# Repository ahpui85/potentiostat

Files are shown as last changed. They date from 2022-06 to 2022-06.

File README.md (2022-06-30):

This project is aimed to design a miniaturized, an inexpensive, and easy to use electrochemical potentiostat to meet the demand for on-site measurement. Integration of the potentiostat to a mobile device makes the measuring device portable. Bluetooth technology is chosen to communicate with mobile device as it features both low power and wireless communication. Therefore the potentiostat consist of the following modules: 
a) Front-end module which drives the sensor and the measures the current. 
b) power module that generates the stable voltage. 
c) A back-end module comprised of microcontroller (MCU) to control voltage, digitize and process the data, and Bluetooth module to communicate with the mobile devices. 
We have created a guide to design, layout, assemble, troubleshoot, and test a Printed circuit board (PCB) that is able conduct electrochemistry measurement. This step by step guide will ultimately allow anyone to develop a portable, accessible, and low-cost potentiostat based on Arduino, together with mobile phone application to control the potentiostat.

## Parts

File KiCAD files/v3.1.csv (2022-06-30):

Reference | Value | Footprint | Datasheet
P1 | Digital | Socket_Arduino_Nano:Socket_Strip_Arduino_1x15
P2 | Analog | Socket_Arduino_Nano:Socket_Strip_Arduino_1x15
R1 | 510ohm | Resistor_THT:R_Axial_DIN0204_L3.6mm_D1.6mm_P7.62mm_Horizontal | ~
R2 | 200ohm | Resistor_THT:R_Axial_DIN0204_L3.6mm_D1.6mm_P7.62mm_Horizontal | ~
R3 | 510ohm | Resistor_THT:R_Axial_DIN0204_L3.6mm_D1.6mm_P7.62mm_Horizontal | ~
R4 | 200ohm | Resistor_THT:R_Axial_DIN0204_L3.6mm_D1.6mm_P7.62mm_Horizontal | ~
R6 | 250ohm | Resistor_THT:R_Axial_DIN0204_L3.6mm_D1.6mm_P7.62mm_Horizontal | ~
R5 | 12k | Resistor_THT:R_Axial_DIN0204_L3.6mm_D1.6mm_P7.62mm_Horizontal | ~
C1 | 100nf | Capacitor_THT:C_Axial_L3.8mm_D2.6mm_P7.50mm_Horizontal | ~
C2 | 470nf | Capacitor_THT:C_Axial_L3.8mm_D2.6mm_P7.50mm_Horizontal | ~
C3 | 470nf | Capacitor_THT:C_Axial_L3.8mm_D2.6mm_P7.50mm_Horizontal | ~
C4 | 10micron | Capacitor_THT:CP_Radial_D5.0mm_P2.00mm | ~
C5 | 10micron | Capacitor_THT:CP_Radial_D5.0mm_P2.00mm | ~
C7 | 10micron | Capacitor_THT:CP_Radial_D5.0mm_P2.00mm | ~
Ufilter1 | LM741 | Package_DIP:DIP-8_W7.62mm | http://www.ti.com/lit/ds/symlink/lm741.pdf
Upoten1 | LM324 | Package_DIP:DIP-14_W7.62mm | http://www.ti.com/lit/ds/symlink/lm2902-n.pdf
J1 | Conn_01x03 | Connector_PinHeader_2.54mm:PinHeader_1x03_P2.54mm_Vertical | ~
IC1 | ICL7660 | Package_DIP:DIP-8_W7.62mm | http://datasheets.maximintegrated.com/en/ds/ICL7660-MAX1044.pdf
IC2 | ICL7660 | Package_DIP:DIP-8_W7.62mm | http://datasheets.maximintegrated.com/en/ds/ICL7660-MAX1044.pdf
C6 | 10micron | Capacitor_THT:CP_Radial_D5.0mm_P2.00mm | ~
P6 | CONN_01X01 | Socket_Arduino_Nano:1pin_Nano
P5 | CONN_01X01 | Socket_Arduino_Nano:1pin_Nano
P4 | CONN_01X01 | Socket_Arduino_Nano:1pin_Nano
P3 | CONN_01X01 | Socket_Arduino_Nano:1pin_Nano
J5 | Conn_01x06_Female | Connector_PinSocket_2.54mm:PinSocket_1x06_P2.54mm_Vertical | ~
J2 | Conn_01x02_Female | Connector_PinSocket_2.54mm:PinSocket_1x02_P2.54mm_Vertical | ~
JP1 | Jumper | TestPoint:TestPoint_2Pads_Pitch2.54mm_Drill0.8mm | ~

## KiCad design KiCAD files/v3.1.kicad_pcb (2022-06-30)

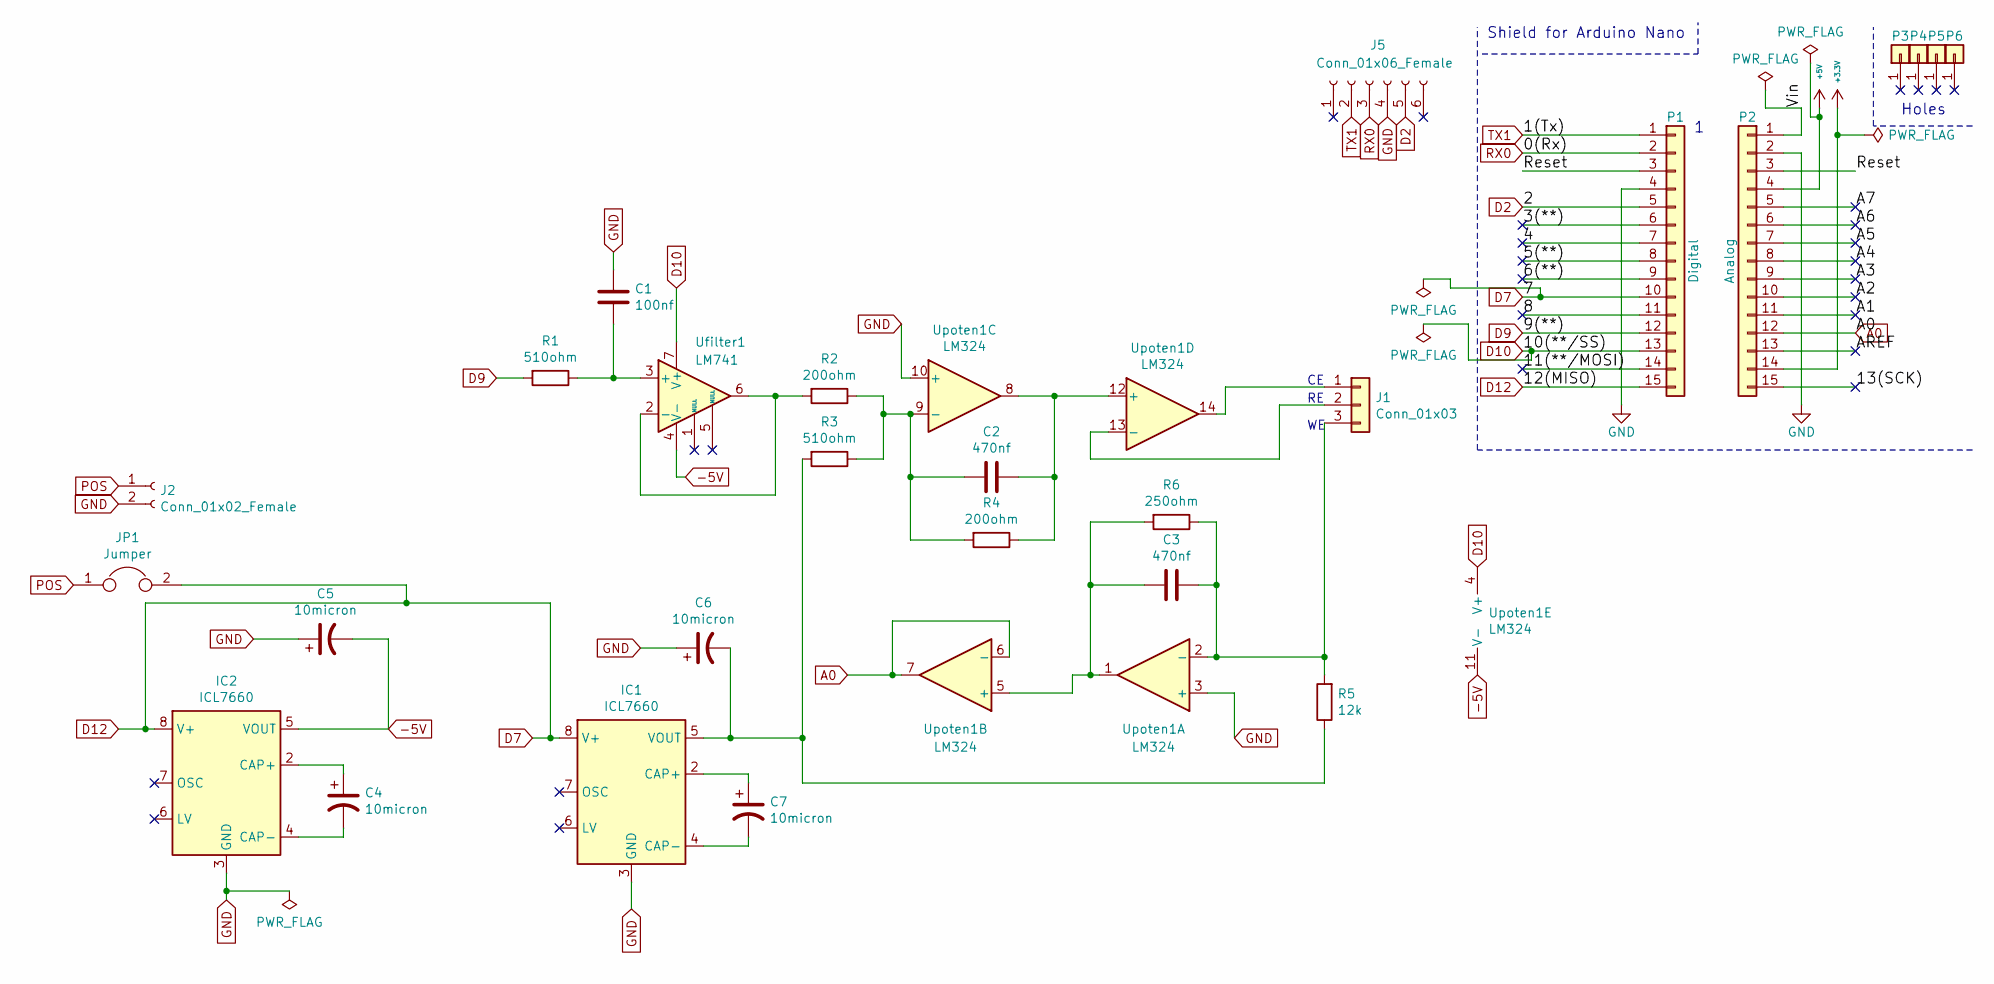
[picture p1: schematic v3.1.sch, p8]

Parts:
C1: 100nf; C_Axial_L3.8mm_D2.6mm_P7.50mm_Horizontal
C2, C3: 470nf; C_Axial_L3.8mm_D2.6mm_P7.50mm_Horizontal
C4, C5, C6, C7: 10micron; CP_Radial_D5.0mm_P2.00mm
IC1, IC2: ICL7660; DIP-8_W7.62mm
J1: Conn_01x03; PinHeader_1x03_P2.54mm_Vertical
J2: Conn_01x02_Female; PinSocket_1x02_P2.54mm_Vertical
J5: Conn_01x06_Female; PinSocket_1x06_P2.54mm_Vertical
JP1: Jumper; TestPoint_2Pads_Pitch2.54mm_Drill0.8mm
P1: Digital; Socket_Strip_Arduino_1x15
P2: Analog; Socket_Strip_Arduino_1x15
P3, P4, P5, P6: CONN_01X01; 1pin_Nano
R1, R3: 510ohm; R_Axial_DIN0204_L3.6mm_D1.6mm_P7.62mm_Horizontal
R2, R4: 200ohm; R_Axial_DIN0204_L3.6mm_D1.6mm_P7.62mm_Horizontal
R5: 12k; R_Axial_DIN0204_L3.6mm_D1.6mm_P7.62mm_Horizontal
R6: 250ohm; R_Axial_DIN0204_L3.6mm_D1.6mm_P7.62mm_Horizontal
Ufilter1: LM741; DIP-8_W7.62mm
Upoten1: LM324; DIP-14_W7.62mm

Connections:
+3V3: P2.14
+5V: P2.4
-5V: C5.2, IC2.5 (VOUT), Ufilter1.4 (V-), Upoten1.11 (V-)
/3(**): P1.6
/4: P1.7
/5(**): P1.8
/6(**): P1.9
/8: P1.11
/11(**/MOSI): P1.14
/13(SCK): P2.15
/A1: P2.11
/A2: P2.10
/A3: P2.9
/A4: P2.8
/A5: P2.7
/A6: P2.6
/A7: P2.5
/AREF: P2.13
/Reset: P1.3, P2.3
/Vin: P2.1
A0: P2.12, Upoten1.6 (-), Upoten1.7
D2: J5.5, P1.5
D9: P1.12, R1.2
D10: P1.13, Ufilter1.7 (V+), Upoten1.4 (V+)
D12: IC1.8 (V+), IC2.8 (V+), JP1.2, P1.10, P1.15
GND: C1.1, C5.1, C6.1, IC1.3 (GND), IC2.3 (GND), J2.2, J5.4, P1.4, P2.2, Upoten1.3 (+), Upoten1.10 (+)
unnamed: C1.2, R1.1, Ufilter1.3 (+)
unnamed: C2.1, R4.1, Upoten1.8, Upoten1.12 (+)
unnamed: C2.2, R2.1, R3.1, R4.2, Upoten1.9 (-)
unnamed: C3.1, J1.3, R5.2, R6.1, Upoten1.2 (-)
unnamed: C3.2, R6.2, Upoten1.1, Upoten1.5 (+)
unnamed: C4.1, IC2.2 (CAP+)
unnamed: C4.2, IC2.4 (CAP-)
unnamed: C6.2, IC1.5 (VOUT), R3.2, R5.1
unnamed: C7.1, IC1.2 (CAP+)
unnamed: C7.2, IC1.4 (CAP-)
unnamed: J1.1, Upoten1.14
unnamed: J1.2, Upoten1.13 (-)
unnamed: R2.2, Ufilter1.2 (-), Ufilter1.6
POS: J2.1, JP1.1
RX0: J5.3, P1.2
TX1: J5.2, P1.1

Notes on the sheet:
Shield for Arduino Nano
Holes

Board: 2 copper layers, 27 parts (0 on the bottom side), 24 nets, no tracks yet.

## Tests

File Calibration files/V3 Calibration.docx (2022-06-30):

Edit TS-V3.1(ard)

Arduino potentiostat calibration Procedures

1. Change the Arduino code to scan voltage range from 0 to 5 V, digital 0 to 255

for(int n = 1; n <= count; n++){

for(int val = 0; val < 255; val++){

analogWrite(a,val);

Troubleshoot the board power problem

2. Connect the board to Arduino nano. Load the Arduino code. Then, measure the voltage value at the output (reference and counter electrode shorted, and ground terminal of voltmeter connect to Arduino nano ground terminal). This is also used to measure voltage at other resistor components and negative voltage regulator supply.

Grounding: Gnd on breadboard -> connect to crocodile clip -> connect to black (machine)

Disconnect WE wire

RE/CE wire crocodile clip to red (machine)/ red(machine) used to check voltage at components

| When (a,0) /V | When (a,1) /V
@R1 | 0 | 4.5
@R2 | 0 | 1.9
@R3 | -3.3 | -3.3
@R4 | 1.3 | -0.5
@R5 | -3.3 | -3.3
@R6 | 0 | 0.8
@C5 | -4.2 | -3.5
@C6 | -3.3 | -3.3
@CE/RE | +1.34 | -0.64

Terminal | On (1)/off (0) | On (1)/off (0)
an | 1 | 1
ap | 1 | 1
a1 | 1 | 1
A (d9) | 0 | 1
Vout | +1.34 | -0.64

3. Run the MIT-app, take note the voltage reading from voltmeter and val.

Digital (val) | 1Voltage (v) | 2Voltage (v) | 3Voltage (v) | Ave Voltage (v)
0 | 1.34 | 1.34 | 1.34 | 1.34
10 | 1.13 | 1.13 | 1.13 | 1.13
20 | 0.96 | 0.96 | 0.96 | 0.96
30 | 0.78 | 0.78 | 0.78 | 0.78
40 | 0.60 | 0.60 | 0.60 | 0.60
50 | 0.42 | 0.40 | 0.42 | 0.41
60 | 0.23 | 0.23 | 0.23 | 0.23
70(@69) | 0 | 0 | 0 | 0
80 | -0.12 | -0.13 | -0.13 | -0.13
90 | -0.31 | -0.31 | -0.31 | -0.31
100 | -0.52 | -0.52 | -0.52 | -0.52
110 | -0.64 | -0.64 | -0.64 | -0.64
120 | -0.64 | -0.64 | -0.64 | -0.64
200 | -0.64 | -0.64 | -0.64 | -0.64
255 | -0.64 | -0.64 | -0.64 | -0.64

Note: The results can tell use the DAC range and DAC resolution. It can calculate the Estep1 parameter value.

voltage value is from +1.34 to -0.64,

voltage range: 1.34 + 0.64 = 1.98

digital range: 0 to 110

so, 1.98v/110=0.0127

Estep1 = Estep1+0.0127 <- change in arduino

4. Plot voltage vs Digital (val). Fit the curve to find the linear equation.

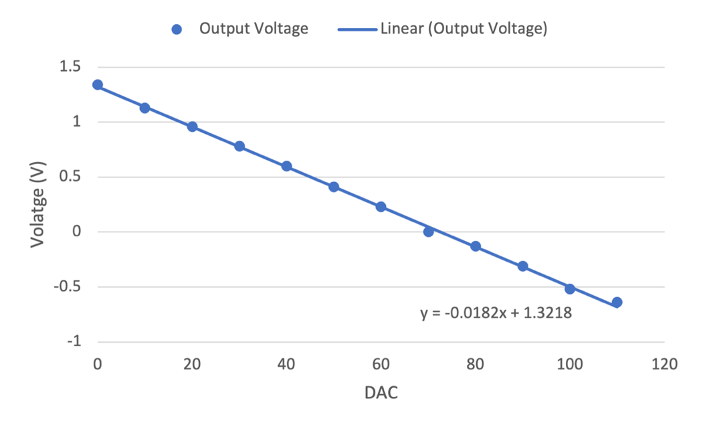
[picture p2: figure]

Fitting equation is Vout=-0.0182x+1.3218

Use this equation to find x, which is translated into Arduino voltage

5. Calculate current limit, Vcvc = iin x R6 ; where Vcvc = 5 V and R6 = 250 ohm,

The limit is iin = 5/250 = 20 mA. Due to voltage converter is only -3.3 V, so, the maximum current is

Imax= 3.3V/R5 = 275 micronA, where R5 is 12k.

Form the truth table

Input | Output (V) | ADC
+ 275 micronA | 0 (where I1 = 0) | 0
0 | 0.06 | 12
-275 micronA | 0.12 | 25

Connect 1Kohm resistor to WE-CE/RE

6. The ct (c=analog(ct) is an integer of ADC value. We need to convert it to voltage, Since ADC is 1024 resolution, 5V/1024 = 4.88V/DAC. Then, the measured current value, cc= 275-(c*19.53); (c=ADC value)

Note: // in micronA, resolution DAC is (5V/1024)/R6=0.01953; R6=250 ohm

7. Calibrate with 1 kOhm resistor.

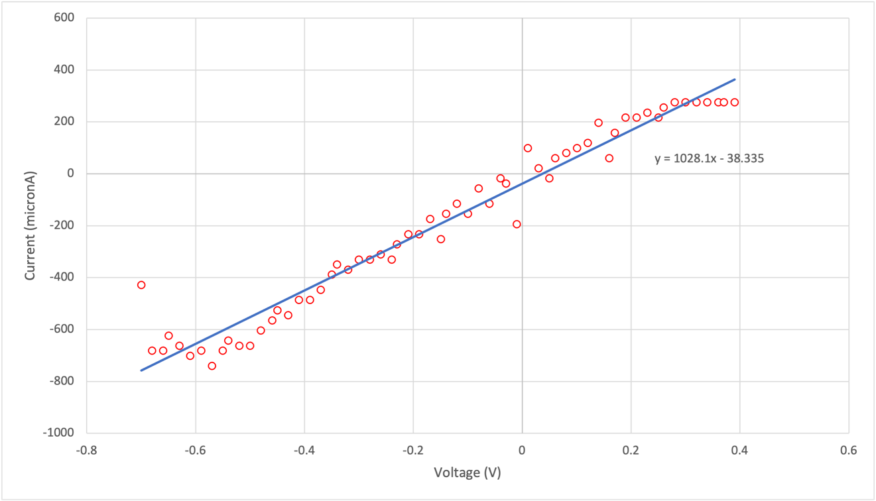
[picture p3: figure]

Fitting equation is current= y = 1028x – 38.335

So, the percentage error is err = (1000- 1/1028 *10⁶)/1000 = 2.7%

To find the upper and lower limit

Set ei = -1400mV, ef= 1000mV

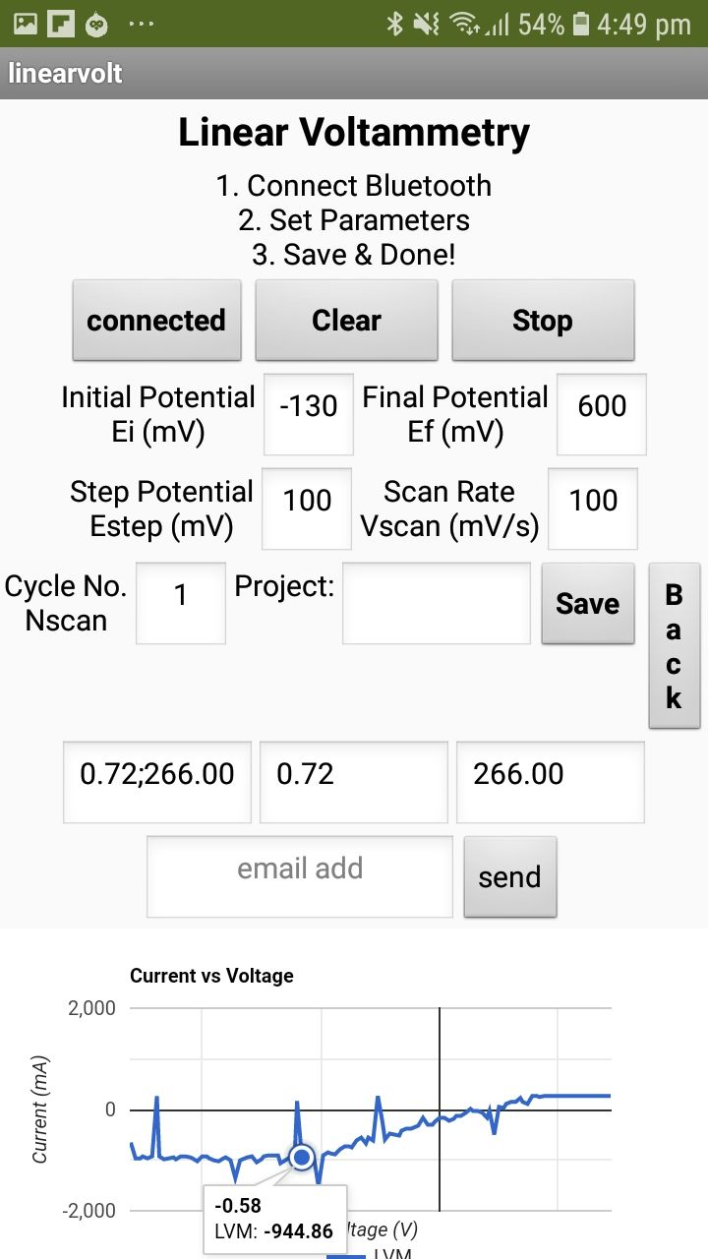
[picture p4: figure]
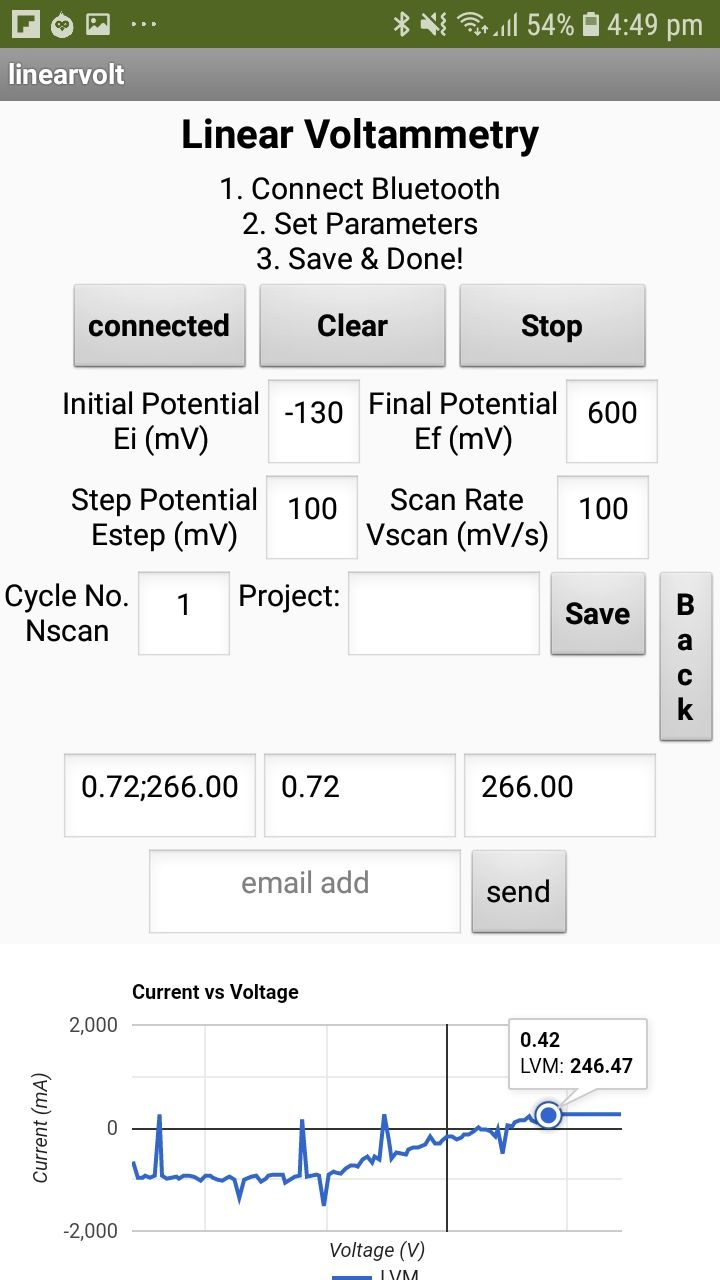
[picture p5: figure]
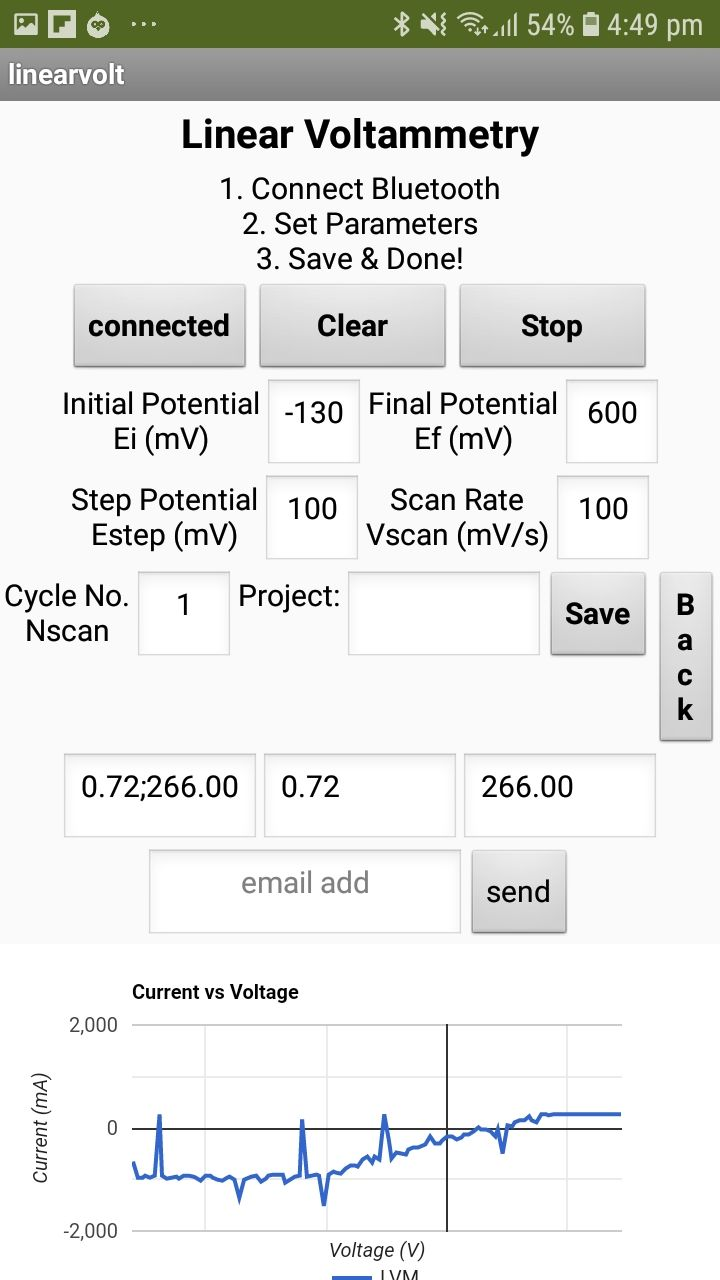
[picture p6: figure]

Narrow down to range: -700mV to 400mV

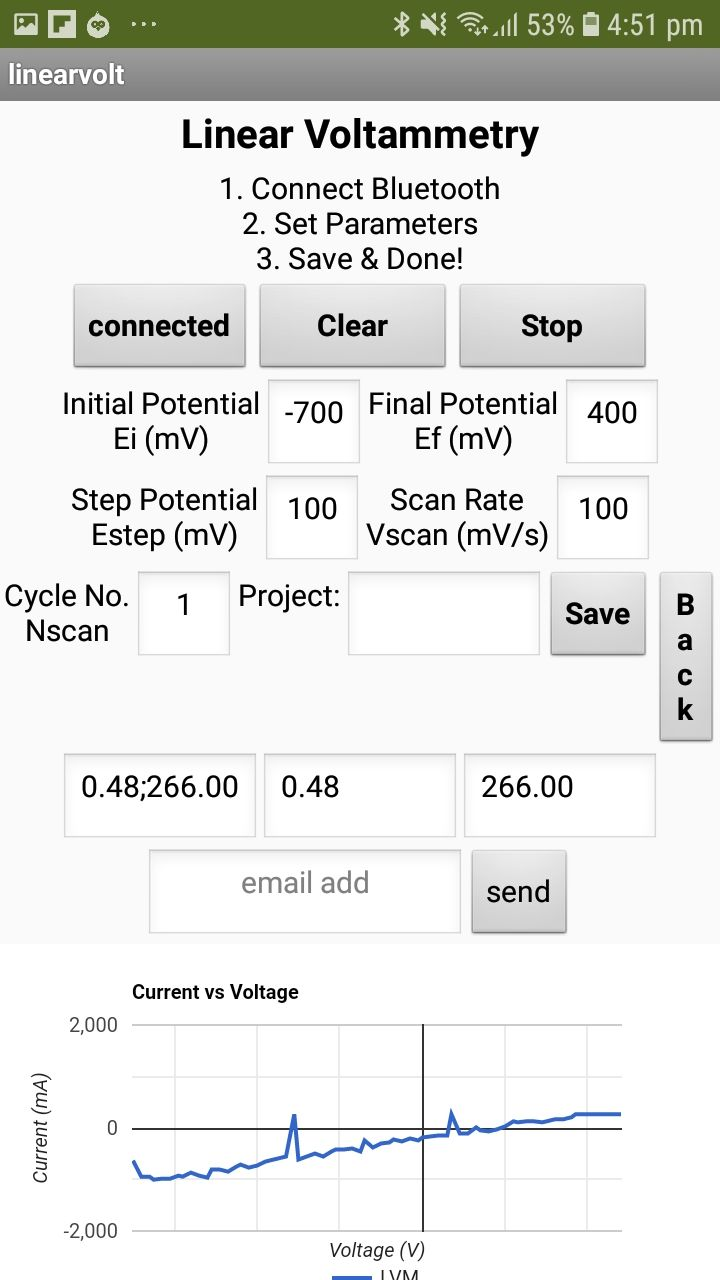
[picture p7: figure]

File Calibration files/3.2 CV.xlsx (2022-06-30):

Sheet: Sheet1
Output Voltage | Fit Output Voltage
0 | 1.34
10 | 1.13
20 | 0.96
30 | 0.78
40 | 0.6
50 | 0.41
60 | 0.23
70 | 0
80 | -0.13
90 | -0.31
100 | -0.52
110 | -0.64

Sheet: Sheet1 (2)
Output Voltage | Fit Output Voltage
0 | 1.26
10 | 1.1
20 | 0.97
30 | 0.76
40 | 0.59
50 | 0.38
60 | 0.2
70 | 0
80 | -0.14
90 | -0.35
100 | -0.54
110 | -0.72
120 | -0.78
130 | -0.78
140 | -0.78

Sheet: 100
-0.70;-3591.94 | -0.70 | -3591.94 | -0.7 | -3591.94
-0.68;-3826.30 | -0.68 | -3826.30 | -0.68 | -3826.3
-0.66;-3806.77 | -0.66 | -3806.77 | -0.66 | -3806.77
-0.65;-1638.94 | -0.65 | -1638.94 | -0.65 | -1638.94
-0.63;-3865.36 | -0.63 | -3865.36 | -0.63 | -3865.36
-0.61;-3845.83 | -0.61 | -3845.83 | -0.61 | -3845.83
-0.59;-3728.65 | -0.59 | -3728.65 | -0.59 | -3728.65
-0.57;-3806.77 | -0.57 | -3806.77 | -0.57 | -3806.77
-0.55;-3670.06 | -0.55 | -3670.06 | -0.55 | -3670.06
-0.54;-3806.77 | -0.54 | -3806.77 | -0.54 | -3806.77
-0.52;-3865.36 | -0.52 | -3865.36 | -0.52 | -3865.36
-0.50;-3650.53 | -0.50 | -3650.53 | -0.5 | -3650.53
-0.48;-3865.36 | -0.48 | -3865.36 | -0.48 | -3865.36
-0.46;-3611.47 | -0.46 | -3611.47 | -0.46 | -3611.47
-0.45;-3787.24 | -0.45 | -3787.24 | -0.45 | -3787.24
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

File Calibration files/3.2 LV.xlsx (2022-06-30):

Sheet: Sheet1
Output Voltage | Fit Output Voltage
0 | 1.34
10 | 1.13
20 | 0.96
30 | 0.78
40 | 0.6
50 | 0.41
60 | 0.23
70 | 0
80 | -0.13
90 | -0.31
100 | -0.52
110 | -0.64

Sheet: Sheet1 (2)
Output Voltage | Fit Output Voltage
0 | 1.26
10 | 1.1
20 | 0.97
30 | 0.76
40 | 0.59
50 | 0.38
60 | 0.2
70 | 0
80 | -0.14
90 | -0.35
100 | -0.54
110 | -0.72
120 | -0.78
130 | -0.78
140 | -0.78

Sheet: 100
-0.70;-3631.00 | -0.70 | -3631.00 | -0.7 | -3631
-0.68;-3845.83 | -0.68 | -3845.83 | -0.68 | -3845.83
-0.66;-3767.71 | -0.66 | -3767.71 | -0.66 | -3767.71
-0.65;-3865.36 | -0.65 | -3865.36 | -0.65 | -3865.36
-0.63;-3904.42 | -0.63 | -3904.42 | -0.63 | -3904.42
-0.61;-3884.89 | -0.61 | -3884.89 | -0.61 | -3884.89
-0.59;-3865.36 | -0.59 | -3865.36 | -0.59 | -3865.36
-0.57;-3865.36 | -0.57 | -3865.36 | -0.57 | -3865.36
-0.55;-3904.42 | -0.55 | -3904.42 | -0.55 | -3904.42
-0.54;-3904.42 | -0.54 | -3904.42 | -0.54 | -3904.42
-0.52;-3826.30 | -0.52 | -3826.30 | -0.52 | -3826.3
-0.50;-3650.53 | -0.50 | -3650.53 | -0.5 | -3650.53
-0.48;-3611.47 | -0.48 | -3611.47 | -0.48 | -3611.47
-0.46;-3552.88 | -0.46 | -3552.88 | -0.46 | -3552.88
-0.45;-3572.41 | -0.45 | -3572.41 | -0.45 | -3572.41
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
